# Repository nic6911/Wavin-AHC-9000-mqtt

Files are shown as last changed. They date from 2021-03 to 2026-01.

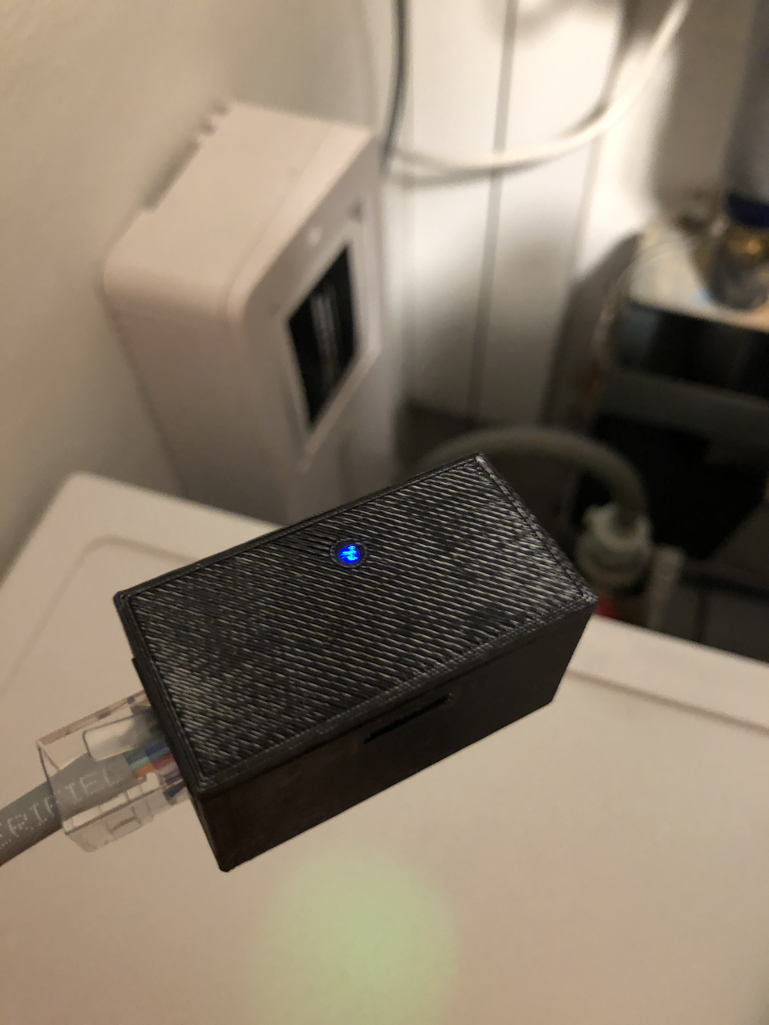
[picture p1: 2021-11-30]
electronics/Rev2_1/module.jpg

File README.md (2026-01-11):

# Wavin-AHC-9000-mqtt
This is a simple mqtt interface for Wavin AHC-9000/Jablotron AC-116, with the goal of being able to control this heating controller from a home automation system. 

## Homey App and install instructions

I have not done this myself as I run Home Assistant - but there's guides from user here:

Homey App from a user (Filip B Bech): https://homey.app/en-dk/app/com.wavin.ahc9000/Wavin-AHC-9000/

Guide from a user (Jan): https://github.com/nic6911/Wavin-AHC-9000-mqtt/blob/master/doc/Homey%20guide%20til%20Wavin%20AHC%209000%20ModBus%20installation.pdf

## Hardware

## ESP32C3
See here: https://github.com/nic6911/ESP32_Modbus_Module

## Software

### ESP32C3
Supporting the ESP32C3 version of the modbus module using MQTT through Arduino

### Video Tutorials
I have made a couple of video tutorials.

For setting up Home Assistant for MQTT, finding the Wavin client and adding zones looke here:
https://youtu.be/kwnt9SaQ6Jc

For the above to work you have to have a programmed ESP device talking modbus. I have made this video tutorial for ESP-01, but similar procedure is viable for the new ESP32-C3.
https://youtu.be/PWJ3N4B8Pc4

### Important config changes

In your configuration.yaml you have to add:
```
mqtt:
  broker: IP address of the MQTT server (so you HA ip)
  username: user name selected previously
  password: password selected previously
  discovery: true
  discovery_prefix: homeassistant  
```
If you do not want automatic discovery of the zones of Wavin then read further down in the readme to see how.

The settings you just added in the MQTT setup is needed in the configuration of the Wavin ESP-01 software.
Go to the PrivateConfig.h and edit the settings:
```
WIFI_SSID = "Enter wireless SSID here";         // wifi ssid (name of your WiFi network)
WIFI_PASS = "Enter wireless password here";     // wifi password

MQTT_SERVER = "Enter mqtt server address here"; // mqtt server address without port number (your HA server address e.g. 192.168.0.1)
MQTT_USER   = "Enter mqtt username here";       // mqtt user. Use "" for no username (just created in the previous video tutorial)
MQTT_PASS   = "Enter mqtt password here";       // mqtt password. Use "" for no password (just created in the previous video tutorial)
MQTT_PORT   = 1883;                             // mqtt port
```

#### Arduino

Install the hardware support for ESP8266 as written in the readme under "Installing with Boards Manager"
https://github.com/esp8266/Arduino
Now, install the PubSubClient by Nick O'Leary through the Arduino Library Manager

#### Important !

When programmed insert the module into the board like shown in the picture and connect it to you AHC9000 using a regular ethernet cable.
IMPORTANT: To ensure a stable running of the switch mode supply, insert the ESP-01 prior to powering the board with the RJ45. A load on the switch mode on board is good for its stability.

### Testing
Assuming you have a working mqtt server setup, you should now be able to control your AHC-9000 using mqtt. If you have the [Mosquitto](https://mosquitto.org/) mqtt tools installed on your mqtt server, you can execude:
```
mosquitto_sub -u username -P password -t heat/# -v
```
to see all live updated parameters from the controller.

To change the target temperature for a output, use:
```
mosquitto_pub -u username -P password -t heat/floorXXXXXXXXXXXX/1/target_set -m 20.5
```
where the number 1 in the above command is the output you want to control and 20.5 is the target temperature in degree celcius. XXXXXXXXXXXX is the MAC address of the Esp8266, so it will be unique for your setup.

### Integration with HomeAssistant
If you have a working mqtt setup in [HomeAssistant](https://home-assistant.io/), all you need to do in order to control your heating from HomeAssistant is to enable auto discovery for mqtt in your `configuration.yaml`.
```
mqtt:
  discovery: true
  discovery_prefix: homeassistant
```
You will then get a climate and a battery sensor device for each configured output on the controller.

If you don't like auto discovery, you can add the entries manually. Create an entry for each output you want to control. Replace the number 0 in the topics with the id of the output and XXXXXXXXXXXX with the MAC of the Esp8266 (can be determined with the mosquitto_sub command shown above)
```
climate wavinAhc9000:
  - platform: mqtt
    name: floor_kitchen
    current_temperature_topic: "heat/floorXXXXXXXXXXXX/0/current"
    temperature_command_topic: "heat/floorXXXXXXXXXXXX/0/target_set"
    temperature_state_topic: "heat/floorXXXXXXXXXXXX/0/target"
    mode_command_topic: "heat/floorXXXXXXXXXXXX/0/mode_set"
    mode_state_topic: "heat/floorXXXXXXXXXXXX/0/mode"
    modes:
      - "heat"
      - "off"
    availability_topic: "heat/floorXXXXXXXXXXXX/online"
    payload_available: "True"
    payload_not_available: "False"
    qos: 0

sensor wavinBattery:
  - platform: mqtt
    state_topic: "heat/floorXXXXXXXXXXXX/0/battery"
    availability_topic: "heat/floorXXXXXXXXXXXX/online"
    payload_available: "True"
    payload_not_available: "False"
    name: floor_kitchen_battery
    unit_of_measurement: "%"
    device_class: battery
    qos: 0
```

## Disclaimer
Do this at your own risk ! You are interfacing with hardware that you can potentially damage if you do not connect things as required !
Using the hardware and code presented here is done at you own risk. The hardware and software has been tested on Wavin AHC9000 and Nilan Comfort 300 without issues.

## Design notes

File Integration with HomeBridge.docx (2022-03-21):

### Integration with HomeBridge

To be able to use the hardware, in HomeBridge, it must be setup with the MQTT software.

There can be other possibilities for success, but this example will work.

If you already have MQTT running go ahead with the Plugin for HomeBridge

If you need to get MQTT I tested this one for Docker, with this Hardware

Eclipse-mosquitto - Official Image | Docker Hub (https://registry.hub.docker.com/_/eclipse-mosquitto/)

Get this Plugin for HomeBridge

https://github.com/arachnetech/homebridge-mqttthing#readme

The setup can easily be change in the UI, but as an example, this can be used for one of the sensors

{

"bridge": {

"name": "My bridge",

"username": "XX:XX:XX:XX:XX:XX",

"port": 52101,

"pin": "XXX-XX-XXX"

},

"accessories": [

{

"type": "thermostat",

"name": "Name_Room",

"url": "mqtt://127.0.0.1:1883",

"debounceRecvms": 200,

"optimizePublishing": false,

"topics": {

"getOnline": "heat/floorXXXXXXXXXXXX/online",

"getBatteryLevel": "heat/floorXXXXXXXXXXXX/0/battery",

"getCurrentHeatingCoolingState": "heat/floorXXXXXXXXXXXX/0/output",

"getCurrentTemperature": "heat/floorXXXXXXXXXXXX/0/current",

"getTargetHeatingCoolingState": "heat/floorXXXXXXXXXXXX/0/mode",

"setTargetHeatingCoolingState": "heat/floorXXXXXXXXXXXX/0/mode_set",

"getTargetTemperature": "heat/floorXXXXXXXXXXXX/0/target",

"setTargetTemperature": "heat/floorXXXXXXXXXXXX/0/target_set",

"getTemperatureDisplayUnits": "CELSIUS "

},

"onlineValue": "on",

"offlineValue": "off",

"confirmationPeriodms": 1000,

"heatingCoolingStateValues": [

"off",

"heat"

],

"restrictHeatingCoolingState": [

0,

1

],

"minTemperature": 12,

"maxTemperature": 40,

"history": true,

"accessory": "mqttthing"

}

]

}

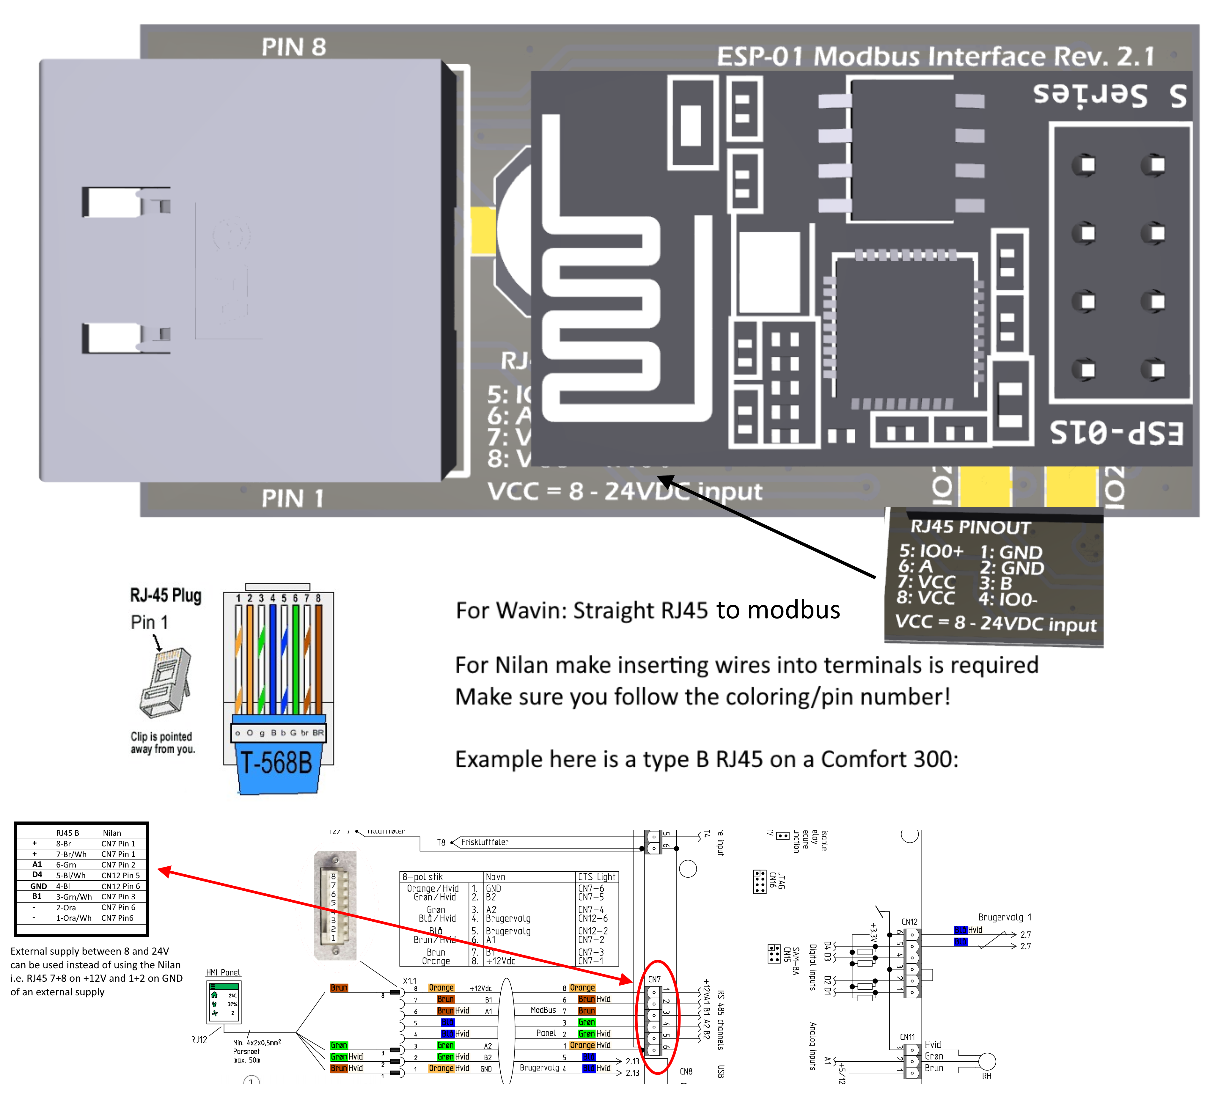
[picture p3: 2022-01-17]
electronics/Rev2_1/Connections.png

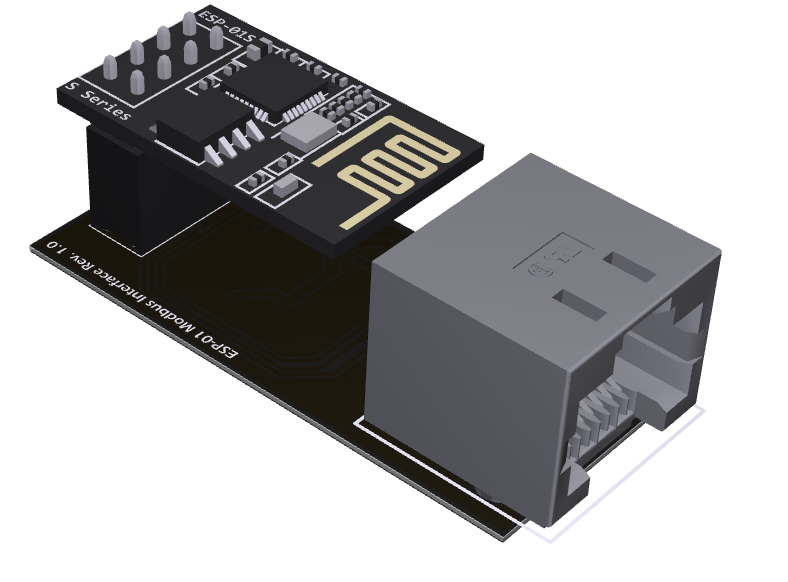
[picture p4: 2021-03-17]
electronics/Top.PNG

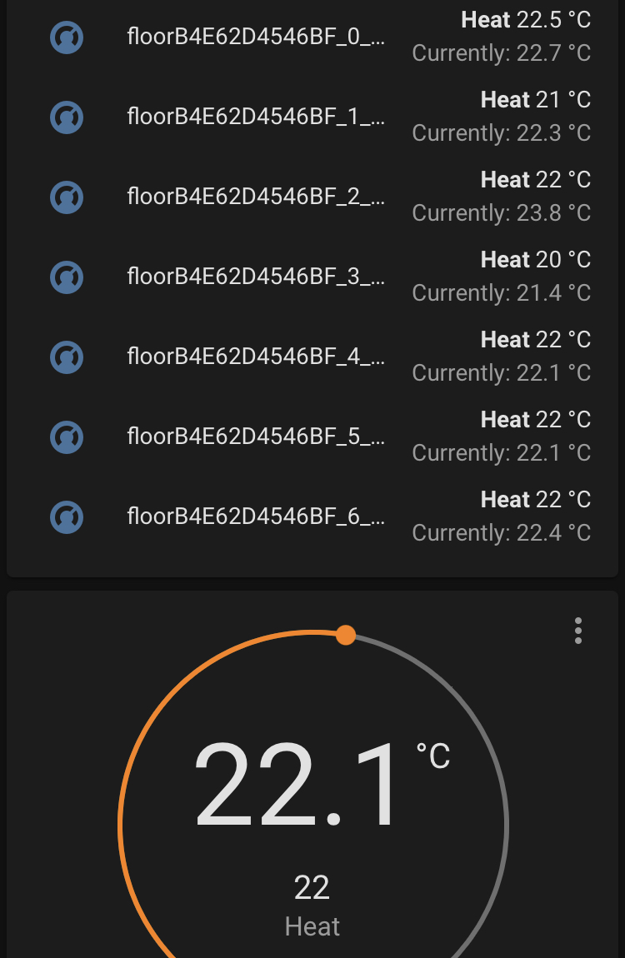
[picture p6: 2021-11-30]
electronics/Rev2_1/IOS_HA.jpg

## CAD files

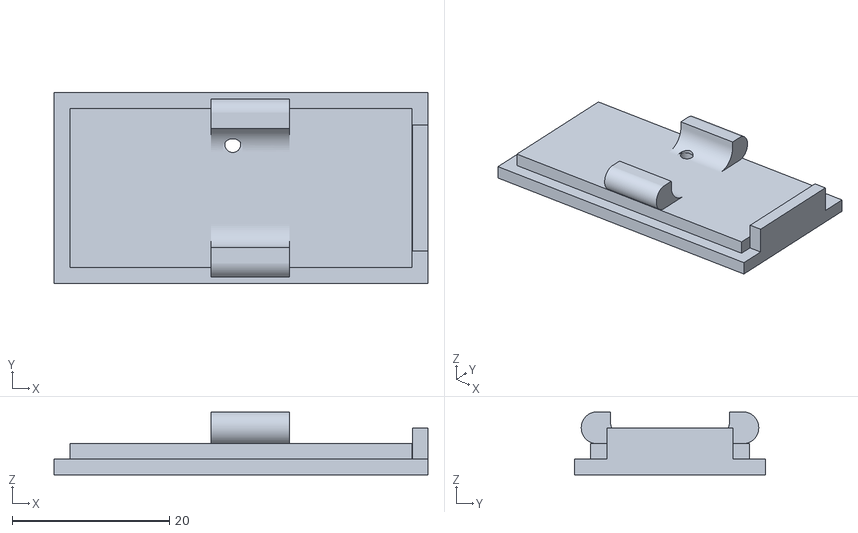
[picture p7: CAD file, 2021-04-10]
casing/Rev2_1/Lid.stl
47.5 x 24.3 x 8.00

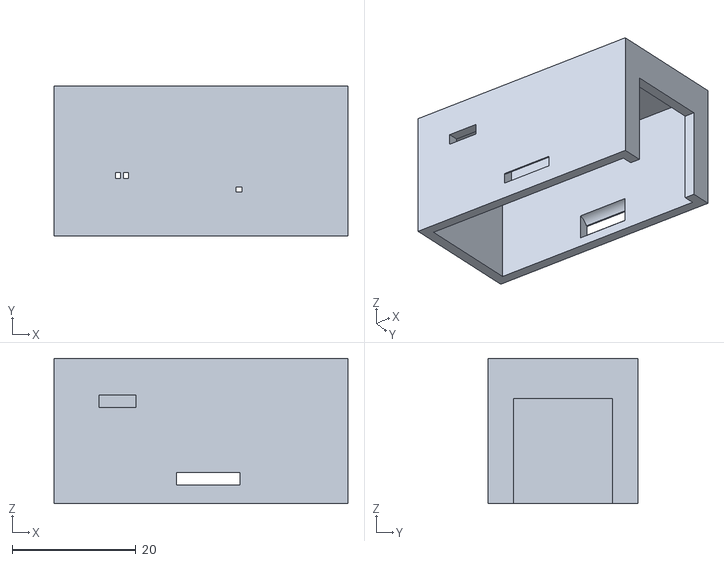
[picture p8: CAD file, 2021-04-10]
casing/Rev2_1/Case.stl
47.5 x 24.3 x 23.5

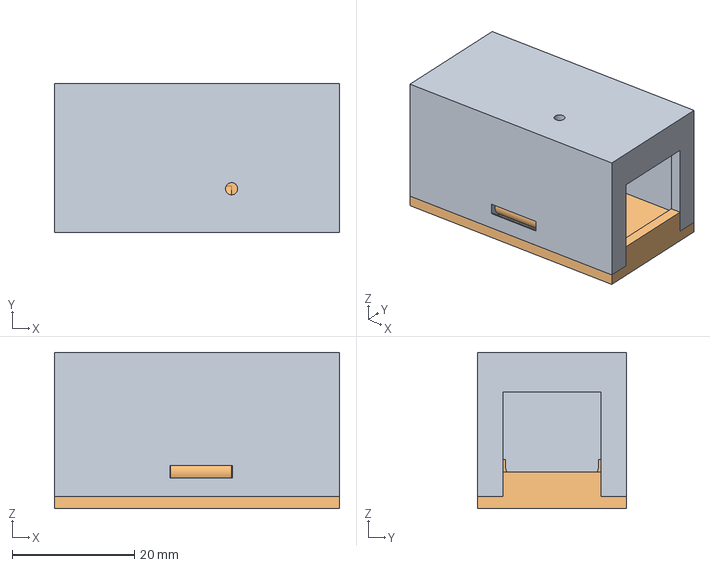
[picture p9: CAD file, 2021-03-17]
casing/Step Model.step
46.5 x 24.3 x 25.5 mm

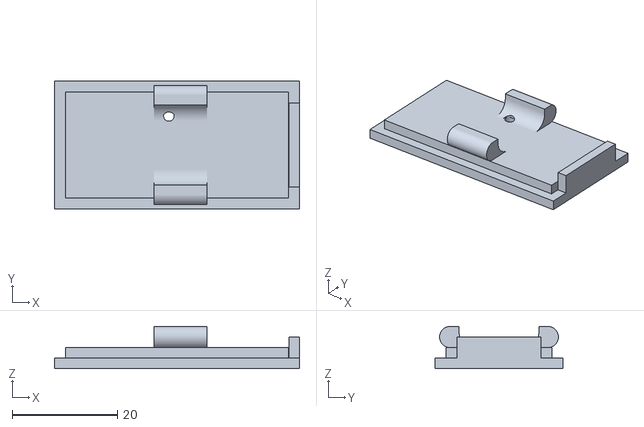
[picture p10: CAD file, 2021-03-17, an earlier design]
casing/Lid.stl
46.5 x 24.3 x 8.00

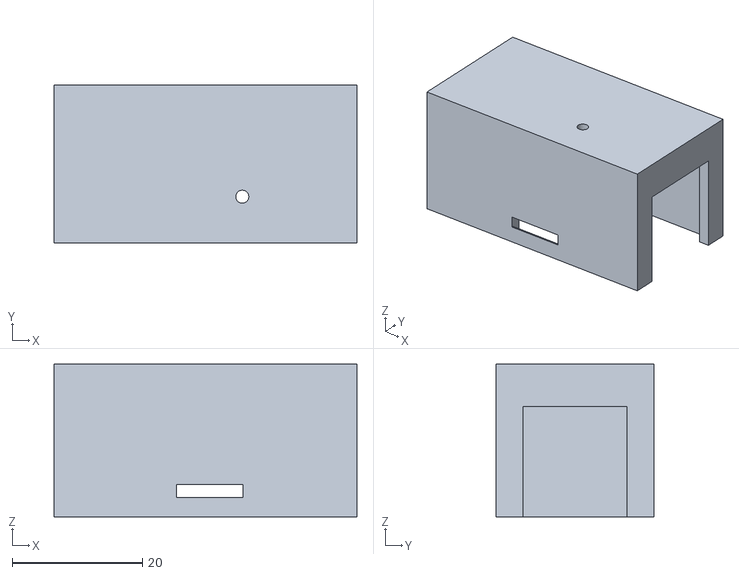
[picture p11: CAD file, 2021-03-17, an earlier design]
casing/Case.stl
46.5 x 24.3 x 23.5

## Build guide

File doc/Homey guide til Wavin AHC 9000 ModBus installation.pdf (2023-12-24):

Wavin AHC 9000 til Homey med ModBus enhed (Windows vejledning)

Bruger denne ModBus: https://www.ustepper.com/shop/#!/products/esphome-modbus-module

Hent og installer: https://www.arduino.cc/en/software

Hent ZIP filen (Code -> Download ZIP file) https://github.com/nic6911/Wavin-AHC-9000-mqtt

Det forvirrede mig, at enheden er en ESP32C3, men installationen virkede for mig kun med ESP8266 softwaren.

Homey step #1:

Installer MQTT Broker: https://homey.app/en-dk/app/nl.scanno.mqttbroker/MQTT-Broker/

Konfigurer app

Angiv port 1883 i ”Enter port number unsecure connections”

Angiv user og Password eks. homey / homey

Save settings og genstart app

Installer Wavin AHC 9000: https://homey.app/en-dk/app/com.wavin.ahc9000/Wavin-AHC-9000/

Konfigurer app

Angiv ip eks: mqtt://192.168.0.100:1833 (din Homey IP)

Hertil dit valgte username og password, save changes og genstart app

Windows:

Unzip filen og gå ind i følgende mappe: Wavin-AHC-9000-mqtt-master\software\ESP8266\Arduino\wavin

Åbn PrivateConfig.h med notepad og ret dine MQTTSERVER oplysninger (Vil mene du faktisk kan vente med dette, da du bliver spurgt om de samme oplysninger, når du tilslutter din ModBus til din Wavin ved at tilgå dens WiFi)

Arduino IDE:
Tilslut din ModBus med USB-C

Åbn wavin.ino fra mappen Wavin-AHC-9000-mqtt-master\software\ESP8266\Arduino\wavin

Tilføj: File –> Preferences –> Additional Boards Manager URLs: https://arduino.esp8266.com/stable/package_esp8266com_index.json

(mere info på: https://github.com/esp8266/Arduino)

Tools -> Board Manager -> Søg efter: “esp32” og installer “esp32 by Espressif Systems”

Tools -> Board Manager -> eps32 -> vælg: DFRobot Beetle ESP32-C3

Sketch -> Include Library -> Manage Libraries -> Søg efter “pubsub” og installer “PubSubClient by Nick O’Leary”

Åbn https://github.com/tzapu/WiFiManager og vælg ”Code” og Download ZIP

Sketch -> Include Library -> Add .ZIP library -> Vælg WiFiManager ZIP filen

Vælg din MobBus enhed Tools -> Port -> Vælg enheden (forbundet med USB-C)

Første ikon under ”File Edit Sketch Tools Help” er verify, den kan du med fordel afvikle, ellers skal du trykke på ikonet ved siden af -> upload – hvis verify går igennem uden fejl.

Wavin

Tilslut din Modbus til din Wavin enhed – herved får den PoE og tænder. Der er to ethernet porte, der begge giver strøm, men kun den ene virker, så din ModBus laver et WiFi kaldet ”MODBUS-MODULE”.

I mit tilfælde var det porten til venstre, set forfra på enheden (de sidder undersænket i bunden af enheden).

Tilslut din mobil til dens WiFi og du vil blive forwarded til dens setup skærm. Du kan nu opsætte WiFi og MQTT serveroplysninger.

Angiv din Homey IP-adresse, username, password samt dine WiFi oplysninger

Homey step #2:

Tilføje enheder, vælg Wavin AHC 9000 og søg efter termostater

Håber det virker.

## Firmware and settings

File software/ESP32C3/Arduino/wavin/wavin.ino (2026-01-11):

#include <FS.h>  
#include <ArduinoJson.h>
#include <WiFi.h>
#include <PubSubClient.h>
#include <ArduinoOTA.h>
#include "WavinController.h"
#include "PrivateConfig.h"
#include "SPIFFS.h"
#include <WiFiManager.h> // https://github.com/tzapu/WiFiManager
WiFiManager wifiManager;

#define HOST "WavinGW-%s" // Change this to whatever you like. 
// MQTT defines
// Esp8266 MAC will be added to the device name, to ensure unique topics
// Default is topics like 'heat/floorXXXXXXXXXXXX/3/target', where 3 is the output id and XXXXXXXXXXXX is the mac
const String   MQTT_PREFIX              = "heat/";       // include tailing '/' in prefix
const String   MQTT_DEVICE_NAME         = "floor";       // only alfanumeric and no '/'
const String   MQTT_ONLINE              = "/online";      
const String   MQTT_SUFFIX_CURRENT      = "/current";    // include heading '/' in all suffixes
const String   MQTT_SUFFIX_SETPOINT_GET = "/target";
const String   MQTT_SUFFIX_SETPOINT_SET = "/target_set";
const String   MQTT_SUFFIX_MODE_GET     = "/mode";
const String   MQTT_SUFFIX_MODE_SET     = "/mode_set";
const String   MQTT_SUFFIX_BATTERY      = "/battery";
const String   MQTT_SUFFIX_OUTPUT       = "/output";

const String   MQTT_VALUE_MODE_STANDBY  = "off";
const String   MQTT_VALUE_MODE_MANUAL   = "heat";

const String   MQTT_CLIENT = "Wavin-AHC-9000-mqtt";       // mqtt client_id prefix. Will be suffixed with Esp8266 mac to make it unique

String mqttDeviceNameWithMac;
String mqttClientWithMac;

// Operating mode is controlled by the MQTT_SUFFIX_MODE_ topic.
// When mode is set to MQTT_VALUE_MODE_MANUAL, temperature is set to the value of MQTT_SUFFIX_SETPOINT_
// When mode is set to MQTT_VALUE_MODE_STANDBY, the following temperature will be used
const float STANDBY_TEMPERATURE_DEG = 5.0;

const uint8_t TX_ENABLE_PIN = 3;
const uint16_t RECIEVE_TIMEOUT_MS = 1000;
WavinController wavinController(TX_ENABLE_PIN, RECIEVE_TIMEOUT_MS);

char chipid[12];
char mqttserver[40]=MQTTSERVER;
char mqttusername[20]=MQTTUSERNAME;
char mqttpassword[20]=MQTTPASSWORD;

WiFiServer server(80);
WiFiClient wifiClient;
PubSubClient mqttClient(wifiClient);

unsigned long lastUpdateTime = 0;

const uint16_t POLL_TIME_MS = 5000;

struct lastKnownValue_t {
  uint16_t temperature;
  uint16_t setpoint;
  uint16_t battery;
  uint16_t status;
  uint16_t mode;
} lastSentValues[WavinController::NUMBER_OF_CHANNELS];

const uint16_t LAST_VALUE_UNKNOWN = 0xFFFF;

bool configurationPublished[WavinController::NUMBER_OF_CHANNELS];


// Read a float value from a non zero terminated array of bytes and
// return 10 times the value as an integer
uint16_t temperatureFromString(String payload)
{
  float targetf = payload.toFloat();
  return (unsigned short)(targetf * 10);
}


// Returns temperature in degrees with one decimal
String temperatureAsFloatString(uint16_t temperature)
{
  float temperatureAsFloat = ((float)temperature) / 10;
  return String(temperatureAsFloat, 1);
}


uint8_t getIdFromTopic(char* topic)
{
  unsigned int startIndex = String(MQTT_PREFIX + mqttDeviceNameWithMac + "/").length();
  int i = 0;
  uint8_t result = 0;

  while(topic[startIndex+i] != '/' && i<3)
  {
    result = result * 10 + (topic[startIndex+i]-'0');
    i++;
  }

  return result;
}


void mqttCallback(char* topic, byte* payload, unsigned int length)
{
  String topicString = String(topic);
  
  char terminatedPayload[length+1];
  for(unsigned int i=0; i<length; i++)
  {
    terminatedPayload[i] = payload[i];
  }
  terminatedPayload[length] = 0;
  String payloadString = String(terminatedPayload);

  uint8_t id = getIdFromTopic(topic);

  if(topicString.endsWith(MQTT_SUFFIX_SETPOINT_SET))
  {
    uint16_t target = temperatureFromString(payloadString);
    wavinController.writeRegister(WavinController::CATEGORY_PACKED_DATA, id, WavinController::PACKED_DATA_MANUAL_TEMPERATURE, target);
  }
  else if(topicString.endsWith(MQTT_SUFFIX_MODE_SET))
  {
    if(payloadString == MQTT_VALUE_MODE_MANUAL) 
    {
      wavinController.writeMaskedRegister(
        WavinController::CATEGORY_PACKED_DATA,
        id,
        WavinController::PACKED_DATA_CONFIGURATION,
        WavinController::PACKED_DATA_CONFIGURATION_MODE_MANUAL,
        ~WavinController::PACKED_DATA_CONFIGURATION_MODE_MASK);
    }
    else if (payloadString == MQTT_VALUE_MODE_STANDBY)
    {
      wavinController.writeMaskedRegister(
        WavinController::CATEGORY_PACKED_DATA, 
        id, 
        WavinController::PACKED_DATA_CONFIGURATION, 
        WavinController::PACKED_DATA_CONFIGURATION_MODE_STANDBY, 
        ~WavinController::PACKED_DATA_CONFIGURATION_MODE_MASK);
    }
  }

  // Force re-read of registers from controller now
  lastUpdateTime = 0;

}


void resetLastSentValues()
{
  for(int8_t i=0; i<WavinController::NUMBER_OF_CHANNELS; i++)
  {
    lastSentValues[i].temperature = LAST_VALUE_UNKNOWN;
    lastSentValues[i].setpoint = LAST_VALUE_UNKNOWN;
    lastSentValues[i].battery = LAST_VALUE_UNKNOWN;
    lastSentValues[i].status = LAST_VALUE_UNKNOWN;
    lastSentValues[i].mode = LAST_VALUE_UNKNOWN;

    configurationPublished[i] = false;
  }
}


void publishIfNewValue(String topic, String payload, uint16_t newValue, uint16_t *lastSentValue)
{
  if (newValue != *lastSentValue)
  {
    if (mqttClient.publish(topic.c_str(), payload.c_str(), true))
    {
        *lastSentValue = newValue;
    }
    else
    {
      *lastSentValue = LAST_VALUE_UNKNOWN;
    }
  }
}


// Publish discovery messages for HomeAssistant
// See https://www.home-assistant.io/docs/mqtt/discovery/
void publishConfiguration(uint8_t channel)
{
  String climateTopic = String("homeassistant/climate/" + mqttDeviceNameWithMac + "/" + channel + "/config");
  String climateMessage = String(
    "{\"name\": \"" +mqttDeviceNameWithMac + "_" + channel +  "_climate\", "
    "\"current_temperature_topic\": \"" + MQTT_PREFIX + mqttDeviceNameWithMac + "/" + channel + MQTT_SUFFIX_CURRENT + "\", " 
    "\"temperature_command_topic\": \"" + MQTT_PREFIX + mqttDeviceNameWithMac + "/" + channel + MQTT_SUFFIX_SETPOINT_SET + "\", " 
    "\"temperature_state_topic\": \"" + MQTT_PREFIX + mqttDeviceNameWithMac + "/" + channel + MQTT_SUFFIX_SETPOINT_GET + "\", " 
    "\"mode_command_topic\": \"" + MQTT_PREFIX + mqttDeviceNameWithMac + "/" + channel + MQTT_SUFFIX_MODE_SET + "\", " 
    "\"mode_state_topic\": \"" + MQTT_PREFIX + mqttDeviceNameWithMac + "/" + channel + MQTT_SUFFIX_MODE_GET + "\", " 
    "\"modes\": [\"" + MQTT_VALUE_MODE_MANUAL + "\", \"" + MQTT_VALUE_MODE_STANDBY + "\"], " 
    "\"availability_topic\": \"" + MQTT_PREFIX + mqttDeviceNameWithMac + MQTT_ONLINE +"\", "
    "\"payload_available\": \"True\", "
    "\"payload_not_available\": \"False\", "
    "\"qos\": \"0\"}"
  );
  
  String batteryTopic = String("homeassistant/sensor/" + mqttDeviceNameWithMac + "/" + channel + "/config");
  String batteryMessage = String(
    "{\"name\": \"" +mqttDeviceNameWithMac + "_" + channel +  "_battery\", "
    "\"state_topic\": \"" + MQTT_PREFIX + mqttDeviceNameWithMac + "/" + channel + "/battery\", " 
    "\"availability_topic\": \"" + MQTT_PREFIX + mqttDeviceNameWithMac + MQTT_ONLINE +"\", "
    "\"payload_available\": \"True\", "
    "\"payload_not_available\": \"False\", "
    "\"device_class\": \"battery\", "
    "\"unit_of_measurement\": \"%\", "
    "\"qos\": \"0\"}"
  );

  mqttClient.publish(climateTopic.c_str(), climateMessage.c_str(), true);  
  mqttClient.publish(batteryTopic.c_str(), batteryMessage.c_str(), true);
  
  configurationPublished[channel] = true;
}

//flag for saving data
bool shouldSaveConfig = false;

//callback notifying us of the need to save config
void saveConfigCallback () {
  shouldSaveConfig = true;
}

void setup()
{
WiFi.mode(WIFI_STA);
  //read configuration from FS json
  if (SPIFFS.begin()) {
    if (SPIFFS.exists("/config.json")) {
      //file exists, reading and loading
      File configFile = SPIFFS.open("/config.json", "r");
      if (configFile) {
        size_t size = configFile.size();
        // Allocate a buffer to store contents of the file.
        std::unique_ptr<char[]> buf(new char[size]);

        configFile.readBytes(buf.get(), size);
#ifdef ARDUINOJSON_VERSION_MAJOR >= 6
        DynamicJsonDocument json(1024);
        auto deserializeError = deserializeJson(json, buf.get());
        serializeJson(json, Serial);
        if ( ! deserializeError ) {
#else
        DynamicJsonBuffer jsonBuffer;
        JsonObject& json = jsonBuffer.parseObject(buf.get());
        json.printTo(Serial);
        if (json.success()) {
#endif
          strcpy(mqttserver, json["mqtt_server"]);
          strcpy(mqttusername, json["mqtt_user"]);
          strcpy(mqttpassword, json["mqtt_pass"]);
        }
      }
    }
  } 
  //end read
  WiFiManagerParameter custom_mqtt_server("server", "mqtt server", mqttserver, 40);
  WiFiManagerParameter custom_mqtt_user("user", "mqtt username", mqttusername, 20);
  WiFiManagerParameter custom_mqtt_pass("password", "mqtt password", mqttpassword, 20);

  //set config save notify callback
  wifiManager.setSaveConfigCallback(saveConfigCallback);
  wifiManager.addParameter(&custom_mqtt_server);
  wifiManager.addParameter(&custom_mqtt_user);
  wifiManager.addParameter(&custom_mqtt_pass);
    //fetches ssid and pass and tries to connect
    //if it does not connect it starts an access point with the specified name
    //and goes into a blocking loop awaiting configuration
    if (!wifiManager.autoConnect("MODBUS-MODULE")) {
      delay(3000);
      //reset and try again, or maybe put it to deep sleep
      ESP.restart();
      delay(5000);
    }

    //read updated parameters
    strcpy(mqttserver, custom_mqtt_server.getValue());
    strcpy(mqttusername, custom_mqtt_user.getValue());
    strcpy(mqttpassword, custom_mqtt_pass.getValue());
    
    //save the custom parameters to FS
    if (shouldSaveConfig) {
    #ifdef ARDUINOJSON_VERSION_MAJOR >= 6
      DynamicJsonDocument json(1024);
    #else
      DynamicJsonBuffer jsonBuffer;
      JsonObject& json = jsonBuffer.createObject();
    #endif
      json["mqtt_server"] = mqttserver;
      json["mqtt_user"] = mqttusername;
      json["mqtt_pass"] = mqttpassword;
    
      File configFile = SPIFFS.open("/config.json", "w");
    
    #ifdef ARDUINOJSON_VERSION_MAJOR >= 6
      serializeJson(json, Serial);
      serializeJson(json, configFile);
    #else
      json.printTo(Serial);
      json.printTo(configFile);
    #endif
      configFile.close();
      //end save
    }
  uint8_t mac[6];
  WiFi.macAddress(mac);

  char macStr[13] = {0};
  sprintf(macStr, "%02X%02X%02X%02X%02X%02X", mac[0], mac[1], mac[2], mac[3], mac[4], mac[5]);

  mqttDeviceNameWithMac = String(MQTT_DEVICE_NAME + macStr);
  mqttClientWithMac = String(MQTT_CLIENT + macStr);

  char host[64];
  //https://github.com/espressif/arduino-esp32/blob/master/libraries/ESP32/examples/ChipID/GetChipID/GetChipID.ino
  uint32_t chipID = 0;
  	for(int i=0; i<17; i=i+8) {
	  chipID |= ((ESP.getEfuseMac() >> (40 - i)) & 0xff) << i;
	}
  sprintf(chipid, "%08X", chipID);
  sprintf(host, HOST, chipid);
  delay(500);
  WiFi.hostname(host);
  ArduinoOTA.setHostname(host);
  ArduinoOTA.onStart([]() {
  });
  ArduinoOTA.onEnd([]() {
  });
  ArduinoOTA.onProgress([](unsigned int progress, unsigned int total) {
  });
  ArduinoOTA.onError([](ota_error_t error) {
  });
  ArduinoOTA.begin();
  server.begin();
  
  mqttClient.setServer(mqttserver, 1883);
  mqttClient.setCallback(mqttCallback);

}


void loop()
{
  ArduinoOTA.handle();
  WiFiClient wifiClient = server.available();

  if (WiFi.status() == WL_CONNECTED)
  {
    if (!mqttClient.connected())
    {
      String will = String(MQTT_PREFIX + mqttDeviceNameWithMac + MQTT_ONLINE);
      if (mqttClient.connect(mqttClientWithMac.c_str(), mqttusername, mqttpassword, will.c_str(), 1, true, "False") )
      {
          String setpointSetTopic = String(MQTT_PREFIX + mqttDeviceNameWithMac + "/+" + MQTT_SUFFIX_SETPOINT_SET);
          mqttClient.subscribe(setpointSetTopic.c_str(), 1);
          
          String modeSetTopic = String(MQTT_PREFIX + mqttDeviceNameWithMac + "/+" + MQTT_SUFFIX_MODE_SET);
          mqttClient.subscribe(modeSetTopic.c_str(), 1);
          
          mqttClient.publish(will.c_str(), (const uint8_t *)"True", 4, true);

          // Forces resending of all parameters to server
          resetLastSentValues();
      }
      else
      {
          return;
      }
    }
  
    // Process incomming messages and maintain connection to the server
    if(!mqttClient.loop())
    {
        return;
    }

    if (lastUpdateTime + POLL_TIME_MS < millis())
    {
      lastUpdateTime = millis();

      uint16_t registers[11];

      for(uint8_t channel = 0; channel < WavinController::NUMBER_OF_CHANNELS; channel++)
      {
        if (wavinController.readRegisters(WavinController::CATEGORY_CHANNELS, channel, WavinController::CHANNELS_PRIMARY_ELEMENT, 1, registers))
        {
          uint16_t primaryElement = registers[0] & WavinController::CHANNELS_PRIMARY_ELEMENT_ELEMENT_MASK;
          bool allThermostatsLost = registers[0] & WavinController::CHANNELS_PRIMARY_ELEMENT_ALL_TP_LOST_MASK;

          if(primaryElement==0)
          {
              // Channel not used
              continue;
          }

          if(!configurationPublished[channel])
          {
            uint16_t standbyTemperature = STANDBY_TEMPERATURE_DEG * 10;
            wavinController.writeRegister(WavinController::CATEGORY_PACKED_DATA, channel, WavinController::PACKED_DATA_STANDBY_TEMPERATURE, standbyTemperature);
            publishConfiguration(channel);
          }

          // Read the current setpoint programmed for channel
          if (wavinController.readRegisters(WavinController::CATEGORY_PACKED_DATA, channel, WavinController::PACKED_DATA_MANUAL_TEMPERATURE, 1, registers))
          {
            uint16_t setpoint = registers[0];

            String topic = String(MQTT_PREFIX + mqttDeviceNameWithMac + "/" + channel + MQTT_SUFFIX_SETPOINT_GET);
            String payload = temperatureAsFloatString(setpoint);

            publishIfNewValue(topic, payload, setpoint, &(lastSentValues[channel].setpoint));
          }

          // Read the current mode for the channel
          if (wavinController.readRegisters(WavinController::CATEGORY_PACKED_DATA, channel, WavinController::PACKED_DATA_CONFIGURATION, 1, registers))
          {
            uint16_t mode = registers[0] & WavinController::PACKED_DATA_CONFIGURATION_MODE_MASK; 

            String topic = String(MQTT_PREFIX + mqttDeviceNameWithMac + "/" + channel + MQTT_SUFFIX_MODE_GET);
            if(mode == WavinController::PACKED_DATA_CONFIGURATION_MODE_STANDBY)
            {
              publishIfNewValue(topic, MQTT_VALUE_MODE_STANDBY, mode, &(lastSentValues[channel].mode));
            }
            else if(mode == WavinController::PACKED_DATA_CONFIGURATION_MODE_MANUAL)
            {
              publishIfNewValue(topic, MQTT_VALUE_MODE_MANUAL, mode, &(lastSentValues[channel].mode));
            }            
          }

          // Read the current status of the output for channel
          if (wavinController.readRegisters(WavinController::CATEGORY_CHANNELS, channel, WavinController::CHANNELS_TIMER_EVENT, 1, registers))
          {
            uint16_t status = registers[0] & WavinController::CHANNELS_TIMER_EVENT_OUTP_ON_MASK;

            String topic = String(MQTT_PREFIX + mqttDeviceNameWithMac + "/" + channel + MQTT_SUFFIX_OUTPUT);
            String payload;
            if (status & WavinController::CHANNELS_TIMER_EVENT_OUTP_ON_MASK)
              payload = "on";
            else
              payload = "off";

            publishIfNewValue(topic, payload, status, &(lastSentValues[channel].status));
          }

          // If a thermostat for the channel is connected to the controller
          if(!allThermostatsLost)
          {
            // Read values from the primary thermostat connected to this channel 
            // Primary element from controller is returned as index+1, so 1 i subtracted here to read the correct element
            if (wavinController.readRegisters(WavinController::CATEGORY_ELEMENTS, primaryElement-1, 0, 11, registers))
            {
              uint16_t temperature = registers[WavinController::ELEMENTS_AIR_TEMPERATURE];
              uint16_t battery = registers[WavinController::ELEMENTS_BATTERY_STATUS]; // In 10% steps

              String topic = String(MQTT_PREFIX + mqttDeviceNameWithMac + "/" + channel + MQTT_SUFFIX_CURRENT);
              String payload = temperatureAsFloatString(temperature);

              publishIfNewValue(topic, payload, temperature, &(lastSentValues[channel].temperature));

              topic = String(MQTT_PREFIX + mqttDeviceNameWithMac + "/" + channel + MQTT_SUFFIX_BATTERY);
              payload = String(battery*10);

              publishIfNewValue(topic, payload, battery, &(lastSentValues[channel].battery));
            }
          }         
        }

        // Process incomming messages and maintain connection to the server
        if(!mqttClient.loop())
        {
            return;
        }
      }
    }
  }
}

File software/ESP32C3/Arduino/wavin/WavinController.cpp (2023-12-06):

#include <WiFi.h>
#include "WavinController.h"
#include <Arduino.h>

WavinController::WavinController(uint8_t pin, uint16_t timeout_ms)
{
  txEnablePin = pin;
  digitalWrite(pin, LOW);
  pinMode(pin, OUTPUT);

  recieveTimeout_ms = timeout_ms;

  Serial1.begin(38400,SERIAL_8N1,20,21);

}


unsigned int WavinController::calculateCRC(uint8_t *frame, uint8_t bufferSize)
{
  uint16_t temp = 0xFFFF;
  bool flag;

  for (uint8_t i = 0; i < bufferSize; i++)
  {
    temp = temp ^ frame[i];
    for (uint8_t j = 1; j <= 8; j++)
    {
      flag = temp & 0x0001;
      temp >>= 1;
      if (flag)
      {
        temp ^= 0xA001;
      }
    }
  }

  return temp;
}


bool WavinController::recieve(uint16_t *reply, uint8_t cmdtype)
{
  uint8_t buffer[RECIEVE_BUFFER_SIZE];
  uint8_t n = 0;
  unsigned long start_time = millis();

  while (millis() - start_time < recieveTimeout_ms)
  {
    while (Serial1.available() && n<RECIEVE_BUFFER_SIZE)
    {
      buffer[n] = Serial1.read();
      n++;

      if (n > 5 &&
        buffer[0] == MODBUS_DEVICE &&
        buffer[1] == cmdtype &&
        buffer[2] + 5 == n)
      {
        // Complete package
        uint16_t crc = calculateCRC(buffer, n);
        if (crc != 0) return false;

        // CRC ok, copy to reply buffer
        for (int j = 0; j < buffer[2] / 2; j++)
        {
          reply[j] = (buffer[3 + j * 2] << 8) + buffer[4 + j * 2];
        }
        return true;
      }
    }
  }
  return false;
}


void WavinController::transmit(uint8_t *data, uint8_t lenght)
{
  // Empty recieve buffer before sending
  while (Serial1.read() != -1);

  digitalWrite(txEnablePin, HIGH);

  Serial1.write(data, lenght);

  Serial1.flush(); // Wait for data to be sent
  delayMicroseconds(250); // Wait for last char to be transmitted

  digitalWrite(txEnablePin, LOW);
}


bool WavinController::readRegisters(uint8_t category, uint8_t page, uint8_t index, uint8_t count, uint16_t *reply)
{
  uint8_t message[8];

  message[0] = MODBUS_DEVICE;
  message[1] = MODBUS_READ_REGISTER;
  message[2] = category;
  message[3] = index;
  message[4] = page;
  message[5] = count;

  uint16_t crc = calculateCRC(message, 6);

  message[6] = crc & 0xFF;
  message[7] = crc >> 8;

  transmit(message, 8);

  return recieve(reply, MODBUS_READ_REGISTER);
}


bool WavinController::writeRegister(uint8_t category, uint8_t page, uint8_t index, uint16_t value)
{
  uint8_t message[10];

  message[0] = MODBUS_DEVICE;
  message[1] = MODBUS_WRITE_REGISTER;
  message[2] = category;
  message[3] = index;
  message[4] = page;
  message[5] = 1;
  message[6] = value >> 8;
  message[7] = value & 0xFF;

  uint16_t crc = calculateCRC(message, 8);

  message[8] = crc & 0xFF;
  message[9] = crc >> 8;

  transmit(message, 10);

  uint16_t reply[1];
  return recieve(reply, MODBUS_WRITE_REGISTER); // Recieve reply but ignore it. Asume it's ok
}

bool WavinController::writeMaskedRegister(uint8_t category, uint8_t page, uint8_t index, uint16_t value, uint16_t mask)
{
  uint8_t message[12];

  message[0] = MODBUS_DEVICE;
  message[1] = MODBUS_WRITE_MASKED_REGISTER;
  message[2] = category;
  message[3] = index;
  message[4] = page;
  message[5] = 1;
  message[6] = value >> 8;
  message[7] = value & 0xFF;
  message[8] = mask >> 8;
  message[9] = mask & 0xFF;

  uint16_t crc = calculateCRC(message, 10);

  message[10] = crc & 0xFF;
  message[11] = crc >> 8;

  transmit(message, 12);

  uint16_t reply[1];
  return recieve(reply, MODBUS_WRITE_MASKED_REGISTER); // Recieve reply but ignore it. Asume it's ok
}

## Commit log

2021-03-17 3d models for casing added
    [Case.stl, Lid.stl, Step Model.step]
2021-03-21 Added Arduino code
    Stuff doesnt always work with platformio on the ESP-01 for some reason...
2021-04-09 Added OTA update in Arduino code
    If WiFi connection cannot be established a webserver is launched for OTA firmware update
2021-04-10 Added description and rev2_1 details
    [Case.stl, Lid.stl]
2021-09-19 added register adresses for floor temperature and dew point
2021-09-20 refactor temperature to airtemperature
2021-09-20 publish floor temperature, humidity and dewpoint if available
2021-09-20 homeassistant discovery for sensor values + move channel up to start from 1 instead of 0
2021-09-21 update server on current network, no AP
2021-09-21 do not retain sensor readings
2022-07-09 updated schematic
2023-12-06 updated with ESP32C3 MQTT code
    as an alternative for the ESPHome integration supporting other smart home systems than Home Assistant
2023-12-24 Install guide for ESP32C3 and Homey
2026-01-11 Change TX_ENABLE_PIN from 10 to 3 for Rev 2 boards
2026-01-11 update readme for esp32 module
